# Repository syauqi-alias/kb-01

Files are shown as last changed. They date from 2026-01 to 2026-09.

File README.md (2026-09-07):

# Komputer Basikal, KB-01

**KB-01** is a high-performance, open-source bike computer built around the Raspberry Pi Compute Module 5. Designed to function like a rugged PDA for cycling, it features NVMe storage, precise GNSS tracking, a full sensor cluster for ML-based dead reckoning, and a robust power management system with 4.5–7 hours of estimated runtime.

## 📋 Specifications

| Feature | Component / Detail |
| :--- | :--- |
| **Core** | Raspberry Pi CM5 (4GB RAM, quad Cortex-A76) |
| **Storage** | 250GB NVMe M.2 2230 (PCIe) |
| **Display** | Waveshare 3.5" LCD (MIPI DSI) |
| **GNSS** | ST Teseo-LIV4F with Taoglas FXP611.07.0092C (Passive Antenna) |
| **IMU** | Bosch BMI270 (Accel/Gyro, SPI) |
| **Magnetometer** | ST LIS2MDL (I2C) |
| **Barometer** | Bosch BMP390 (I2C) |
| **Temp/Humidity** | Sensirion SHT40 (I2C) |
| **Wheel Speed** | TI DRV5023FA (Continuous unipolar Hall switch, 30kHz BW) |
| **Battery** | 10,000mAh Li-ion 1160100 (3.7V / 37Wh) |
| **Charger** | TI BQ25895 (I2C-configurable, USB BC1.2 detection) |
| **Fuel Gauge** | Maxim MAX17048 (I2C) |
| **Boost Converter** | TI TPS61022 (5V output, 8A valley current limit) |
| **USB Mux** | TI TS3USB30E (2:1 USB 2.0, auto-switching via BQ25895 DSEL) |
| **User Input** | Rotary encoder (A/B + push) + 2 buttons |
| **Audio** | Passive electromagnetic buzzer (PWM-driven via 2N7002 N-FET) |
| **Connectivity** | USB 2.0 (device/peripheral mode for GPX file transfer + charging) |

## ⚡ Power System

The power architecture handles high current loads from the CM5 and NVMe while ensuring safe battery management.

```
USB-C → BQ25895 (VBUS) → SYS → TPS61022 (VIN) → 5V → CM5
                ↕
            Battery
```

* **Charger / Power Path:** [TI BQ25895](https://www.ti.com/product/BQ25895)
    * Charges the battery while simultaneously powering the system via SYS rail.
    * Integrated USB BC1.2 detection for automatic source identification (SDP/CDP/DCP).
    * Input Current Optimizer (ICO) negotiates maximum power from USB source.
    * Ship mode via BATFET for zero-quiescent shutdown.
* **Fuel Gauge:** [Maxim MAX17048](https://www.analog.com/en/products/max17048.html)
    * ModelGauge algorithm — no sense resistor required.
    * Provides accurate SoC% and voltage reporting over I2C.
* **Boost Converter:** [TI TPS61022](https://www.ti.com/product/TPS61022)
    * Provides a fixed 5V output from 3.0–4.5V battery input.
    * EN tied to VIN (always on when SYS is live); MODE tied to GND (PFM for light-load efficiency).
    * Feedback resistors: R1 = 732kΩ, R2 = 100kΩ (per TI reference design).
* **USB-C:**
    * CC1/CC2: 5.1kΩ pull-downs to GND (sink device).
    * D+/D−: Routed via TS3USB30E multiplexer — Channel 1 to BQ25895 (BC1.2 detection), Channel 2 to CM5 USB (data transfer).
    * Mux control: BQ25895 DSEL pin drives TS3USB30E SEL (automatic, no GPIO needed).
    * CM5 USB configured as device/peripheral via `dtoverlay=dwc2,dr_mode=peripheral`.
* **Battery Life:** ~4.5 hours (max load) to ~7 hours (typical load).

## 🔌 Bus Architecture

| Bus | GPIOs | Devices | Notes |
| :--- | :--- | :--- | :--- |
| **I2C1** | GPIO2/3 | BQ25895, MAX17048 | 1.8kΩ built-in pull-ups (do NOT add external) |
| **I2C2** | GPIO4/5 | LIS2MDL, BMP390, SHT40 | 4.7kΩ external pull-ups required |
| **SPI0** | GPIO8–11 | BMI270 | Mode 0, max 10MHz |
| **UART0** | GPIO14/15 | Teseo-LIV4F | 9600 baud default, TX/RX crossover |
| **DSI0** | DISP0 connector | Waveshare 3.5" | Copied from CM5 IO board |
| **PCIe** | PCIe connector | NVMe SSD | Copied from CM5 IO board |

## 📡 Sensor Cluster & ML Dead Reckoning

The sensor cluster enables ML-based location prediction when GNSS is unavailable (tunnels, dense tree cover, urban canyons).

* **Inputs:** BMI270 (acceleration/rotation), LIS2MDL (heading), BMP390 (altitude), DRV5023FA (wheel speed/distance)
* **Ground truth:** Teseo-LIV4F GNSS position during training
* **Approach:** Extended Kalman filter or RNN; wheel speed removes velocity drift ambiguity
* **Wheel Speed Sensor:** DRV5023FA is a continuous-sensing unipolar Hall switch (not sampled) with 30kHz bandwidth — it never misses a pulse regardless of wheel speed. Single south-facing magnet on spoke, open-drain output with 10kΩ pull-up.

## 🔊 Audio Alerts

A passive electromagnetic buzzer (e.g. MLT-8530) driven by PWM on GPIO7 through a 2N7002 N-channel MOSFET. Used for turn-by-turn navigation alerts, speed warnings, button feedback, and low battery warnings.

```
GPIO7 → 100Ω → gate ──┬── 2N7002 drain ──── Buzzer (−)
                       │                          │
                     10kΩ                     Buzzer (+) → 3.3V
                       │                          │
                      GND              1N4148 ──|◄──┘ (flyback diode)
```

## 🖥️ Software Architecture

* **Language:** C (with pthreads for multi-core)
* **GUI:** LVGL (renders directly to framebuffer, no X11/Wayland)
* **Kernel:** PREEMPT_RT patched Linux for deterministic interrupt handling
* **Core allocation:**
    * Core 0 — UI rendering + wheel speed ISR (highest priority)
    * Core 1 — Sensor acquisition (I2C/SPI reads)
    * Core 2 — GNSS processing (UART/NMEA parsing)
    * Core 3 — ML inference + data logging

## 🛠️ Hardware Design Notes

* **Space Optimization:** The boost converter is placed underneath the M.2 NVMe drive clearance to minimize the PCB footprint.
* **Antenna:** Uses a passive flexible polymer antenna (Taoglas FXP611) for GNSS.
* **Mounting:** Designed to accommodate standard 3.5" display mounting points.
* **GPIO0:** Left as spare — HAT EEPROM pin (I2C0/ID_SD), available for future expansion.

### Layer Stackup (6-layer, 1.6 mm, AISLER)

Stackup source: [AISLER 6-layer 1.6 mm 35 µm](https://community.aisler.net/t/6-layers-1-6mm-35-m-stackup/5458). Copper is 35 µm on all layers. Impedance-controlled nets stay on the outer layers only, referenced to the adjacent solid GND plane (same approach as the Raspberry Pi CM5 IO board).

```
Layer    Role                     Reference   Dielectric below
F.Cu     Signal — low-speed       In1 GND     2 × 2116 prepreg, 230 µm, Er 4.25
In1.Cu   GND plane — never split  —           FR4 core,          300 µm, Er 4.5
In2.Cu   Signal — GPIO / SD / I2C In1 GND     3 × 2116 prepreg, 345 µm, Er 4.25
In3.Cu   Power — split pours      —           FR4 core,          300 µm, Er 4.5
In4.Cu   GND plane — never split  —           2 × 2116 prepreg, 230 µm, Er 4.25
B.Cu     Signal — high-speed      In4 GND     —
```

* **B.Cu (high-speed side):** CM5 module, M.2 NVMe, DSI connector, Teseo GNSS and SMA are all on B.Cu, so PCIe, DSI0 and the GNSS RF trace route bottom-to-bottom with no layer changes. Net classes: `DP_90_Outer` (PCIe, USB 2.0), `DP_100_Outer` (DSI0), `SE_50_Outer` (GNSS RF).
* **F.Cu:** USB-C, charger, fuel gauge, sensors, UI. USB 2.0 D+/D− (J3 → TS3USB30E → BQ25895) stays on F.Cu.
* **In2.Cu:** route predominantly one axis (along the 120 mm dimension) — it faces In3 with no plane between them.
* **In3.Cu:** pours only, no traces: `+5V`, `Vsys`, `+3V3`, `VBUS`, `+1.8v`, `3.3V_GNSS`, `M.2_3v3`.
* **Stitching:** via fence between In1 and In4 along the RF trace and around the CM5 high-speed region. Fill unused In2 area with GND to balance copper against In3.

See [ROUTING.md](ROUTING.md) for the routing order and per-net constraints.

## ⚙️ config.txt

```ini
dtparam=i2c_arm=on
dtoverlay=i2c2-pi5,pins_4_5
dtparam=spi=on
enable_uart=1
dtoverlay=dwc2,dr_mode=peripheral
```

## ⚠️ Disclaimer

This project is currently in the **prototype/brainstorming phase**.

* Battery life estimates (4.5–7 hours) are theoretical and based on datasheet typical values.
* USB-PD is not supported with passive CC resistors (5V input only).
* The CM5 + NVMe combination draws significant power — consider NVMe power states for optimisation.

## 🔗 References & Credits

* Designed by [Syauqi Alias](https://syauqi-alias.github.io/)
* Read the full project log here: [Projects Brainstorming](https://syauqi-alias.github.io/jekyll/2023-06-10-idea.html#komputer-basikal-kb-01-bike-computer)

## 📄 License

[MIT License](LICENSE)

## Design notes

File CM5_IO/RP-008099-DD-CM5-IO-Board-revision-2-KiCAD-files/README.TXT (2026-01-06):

These files have been created in version 9 of KiCAD.

Some of the 3d models need to be downloaded form the following places and put into the CM5IO.3shapes directory some models are approximations.

https://datasheets.raspberrypi.org/cm5/CM5-step.zip
https://www.molex.com/molex/products/part-detail/memory_card_socket/5033981892

The models provided in the 3dmodels directory are from various manufacturers including Diodes, Hirose, MTCONN, Toby, TRXCOM. Terms and conditions for the use of the models remain with the original manufacture.

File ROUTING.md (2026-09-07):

# KB-01 Routing Priority

This document is the order in which to route the KB-01 board, and the constraints for each group of nets.

It assumes the layer stackup in [README.md → Layer Stackup](README.md#layer-stackup-6-layer-16-mm-aisler) and the net classes defined in `KB-01_kicad/KB-01/KB-01.kicad_pro` (`SE_50_Outer`, `DP_90_Outer`, `DP_100_Outer`). Board coordinates below are KiCad board coordinates in mm.

**Principle:** route what cannot bend before what can. RF and differential pairs need straight, unbroken paths on an empty board. GPIO can snake around them later.

```
Tier 0  Planes + CM5 escape   foundation — nothing else is valid without these
Tier 1  GNSS RF               1 net, zero tolerance
Tier 2  PCIe                  3 pairs, tightest matching
Tier 3  DSI0                  5 pairs, clock-to-data matching
Tier 4  Switcher hot loops    tiny, local, but fix component placement
Tier 5  USB 2.0               3 pairs, one crosses sides
Tier 6  Power distribution    wide pours + via arrays
Tier 7  Buses                 SPI, I2C, UART, SD, SUSCLK
Tier 8  GPIO / UI / LEDs      anything goes
   —    Leftovers             do not route — delete from schematic
```

## Layer roles (summary)

```
F.Cu     Signal — low-speed       ref In1 GND
In1.Cu   GND plane — never split
In2.Cu   Signal — GPIO / SD / I2C ref In1 GND
In3.Cu   Power — split pours
In4.Cu   GND plane — never split
B.Cu     Signal — high-speed      ref In4 GND
```

**B.Cu is the high-speed side.** The CM5 module, M.2 socket J8, DSI connector J1, Teseo GNSS U6 and SMA J15 are all on B.Cu. PCIe, DSI0 and the GNSS RF trace route bottom-to-bottom with no layer change.

---

## Tier 0 — Planes and CM5 escape

Do this before the first trace.

- Pour **GND on In1.Cu and In4.Cu**, full board, **no splits**. Every impedance number in the net classes assumes a solid plane directly under the trace.
- Plan the **CM5 escape** (204 pads, B.Cu, roughly X 49–105, Y 97–134).
  - High-speed pairs (PCIe, DSI0, USB) exit straight out on B.Cu.
  - GPIO drops to In2 through vias.
  - Reserve clear B.Cu exit lanes for the high-speed pads. Do not place vias in those lanes.

## Tier 1 — GNSS RF

- Net: `Net-(D5-A1)` — add the net label **`GNSS_RF`** in `gnss.kicad_sch` so the name survives re-annotation.
- Path: **U6 RF_IN → D5 → J15 SMA**, all B.Cu, ~12 mm. U6 at (136.1, 50.2), D5 at (132.4, 43.2), J15 at (132.8, 38.6).
- Class: `SE_50_Outer`, **0.395 mm**, referenced to In4.
- Rules:
  - Straight line. No vias. No bends sharper than 45°.
  - No other copper on B.Cu within ~3× trace width (≈1.2 mm) either side.
  - **Via fence** both sides, B.Cu GND pour to In4, ~1.5 mm pitch.
  - Trace passes **through** the D5 ESD pad; no stub branching off.
- Why first: it is the only net where a 1 mm detour measurably costs receiver sensitivity.

## Tier 2 — PCIe

- Nets: `/CM5_high_speed/PCIE_TX_P/N`, `PCIE_RX_P/N`, `PCIE_CLK_P/N`.
- Path: CM5 (B.Cu) → **J8 M.2** at (92.3, 51.4), ~45 mm, B.Cu.
- Class: `DP_90_Outer`, **0.23 mm / 0.12 mm gap**.
- Rules:
  - **Intra-pair skew ≤ 0.1 mm.** No inter-pair matching needed for a single lane.
  - Zero vias if at all possible — both ends are on B.Cu. If a via is unavoidable, one per line, side by side, with a GND stitching via within 1 mm.
  - Pair-to-pair spacing ≥ 3× gap. Keep clear of the DSI pairs.
- Note: the RPi CM5 IO board uses 0.147 mm on a 90 µm dielectric. KB-01 is wider because AISLER's outer prepreg is 230 µm. That is expected — do not "fix" it.
- M.2 lanes 1–3 are intentionally unconnected. Only lane 0 is wired.

## Tier 3 — DSI0

- Nets: `/CM5_high_speed/DPHY0_C_P/N`, `DPHY0_D0..D3_P/N`.
- Path: CM5 (B.Cu) → **J1** at (70.05, 79.4), B.Cu.
- Class: `DP_100_Outer`, **0.18 mm / 0.13 mm gap**.
- Rules:
  - **Intra-pair ≤ 0.1 mm.**
  - **Data-to-clock lane match within ~0.5 mm.**
  - Stay on B.Cu, no vias.
- Why after PCIe: more pairs, slightly more tolerant — DSI bends around PCIe, not the other way round.

## Tier 4 — Switching converter hot loops

Only a few mm each, but they dictate cap and inductor placement. Route them while parts can still be nudged.

- **TPS61022 boost** — U4 at (88.1, 138.3), L2 at (91.5, 144.3), caps C16–C22, all B.Cu.
  - Loop: SW pin → L2 → VOUT cap → GND → PGND pin.
  - Keep on one layer, shortest possible. Cap GND pads drop straight into In4 with 2+ vias each.
- **BQ25895 charger** — U1 at (115.7, 145.2), L1 at (120.0, 136.8), input/output caps, all F.Cu.
  - Same treatment, referenced to In1.
- **Switch nodes** `Net-(U4-SW)` and `Net-(U10-LX)`: short, fat polygons. Never long traces. Never under the RF trace or the U9 oscillator.

## Tier 5 — USB 2.0

- Nets: `/Battery_charger/USB_D+/−`, `MUX_D+/−`, `CHG_D+/−`.
- Path: **J3 USB-C** (F.Cu, 103.6, 153.0) → **U2 TS3USB30E** (F.Cu, 103.3, 143.7) → **U1 BQ25895** (F.Cu) for BC1.2. All F.Cu, short.
- The mux's second channel goes to the **CM5 on B.Cu** — that one pair crosses sides.
  - Two signal vias side by side.
  - One GND stitching via beside them, so return current has a path from In1 to In4.
- Class: `DP_90_Outer`. **Intra-pair ≤ 0.5 mm** — USB 2.0 is forgiving.

## Tier 6 — Power distribution

Biggest current first.

```
BAT+  J4 (127, 150) → U1          F.Cu polygon, ~11 mm, ≥3 mm wide
VBUS  J3 → U1                     F.Cu polygon, ~13 mm, 2–3 mm wide
Vsys  U1 (F.Cu) → U4 (B.Cu)       F.Cu → In3 pour → B.Cu; via array, 6+ vias 0.8/0.4
+5V   U4 → CM5                    B.Cu polygon, ~5 mm — shortest heavy run on the board
Rails +3V3, +1.8v, 3.3V_GNSS,     In3 split pours, fed from CM5 / regulators,
      M.2_3v3                     delivered to F.Cu consumers via 2 vias each
```

- Vsys crossing sides is where a **via array** genuinely matters — a single via is a ~1 A bottleneck.
- Pour In3 last within this tier, after the outer polygons exist, so it is clear which rails still need an inner path.
- Track-width presets for current are in Board Setup → Pre-defined Sizes (0.5 mm ≈ 2 A … 3.0 mm ≈ 7 A, outer layer, 20 °C rise).

## Tier 7 — Buses (mostly In2.Cu)

- **SPI → BMI270** (U12, F.Cu, 103.6, 79.6). Up to 10 MHz — fastest bus on the board. Keep SCK short, no stubs.
- **I2C** → LIS2MDL, BMP581, SHT40, MAX17048, BQ25895. Star or daisy-chain; keep total SDA/SCL length sensible.
- **UART → Teseo** (CM5 B.Cu → U6 B.Cu). Can stay on B.Cu.
- **SD bus** `SD_CLK/CMD/DAT0–3` → J14 (136.5, 90.6). Route as a bundle, match within ~5 mm.
- **SUSCLK**: U9 32.768 kHz oscillator (B.Cu, 82.9, 60.6) → J8. Short. Keep the trace from heading toward L5 (74.4, 51.5).
- **In2 one-axis rule**: mostly vertical runs (along the 120 mm dimension). Jog horizontally on F.Cu or B.Cu. In2 faces In3 with no plane between them.

## Tier 8 — GPIO, UI, sense lines

- Encoder SW3, key switches SW4/SW5, buzzer LS1, power button SW2, LEDs, PPS.
- **Sense lines** — BQ25895 TS / ILIM, MAX17048 `Fuel_G`: short, away from switch nodes. Otherwise unconstrained.

## Do not route

These nets have no destination on this board. They were carried over from the CM5 IO board copy.

```
HDMI0_*   HDMI1_*   USB3-0-*   USB3-1-*   TRD0..3_*   DPHY1_*  (J13)
```

Delete them from `CM5_high_speed.kicad_sch` and `CM5_GPIO.kicad_sch`, and remove J13, **before Tier 0** — otherwise the CM5 escape plan reserves lanes for dead nets, and DRC flags them as unconnected forever.

## Pre-flight checklist

- [ ] Leftover nets and J13 removed from the schematic
- [ ] `GNSS_RF` net label added in `gnss.kicad_sch`
- [ ] GND pours on In1.Cu and In4.Cu, filled, no splits
- [ ] Board Setup → Net Classes → Assignments resolves PCIe → `DP_90_Outer`, DPHY0 → `DP_100_Outer`, RF → `SE_50_Outer`
- [ ] KiCad closed before any external edit to `.kicad_pro` / `.kicad_pcb` / `.kicad_sch`
- [ ] DRC shows no new errors after each tier

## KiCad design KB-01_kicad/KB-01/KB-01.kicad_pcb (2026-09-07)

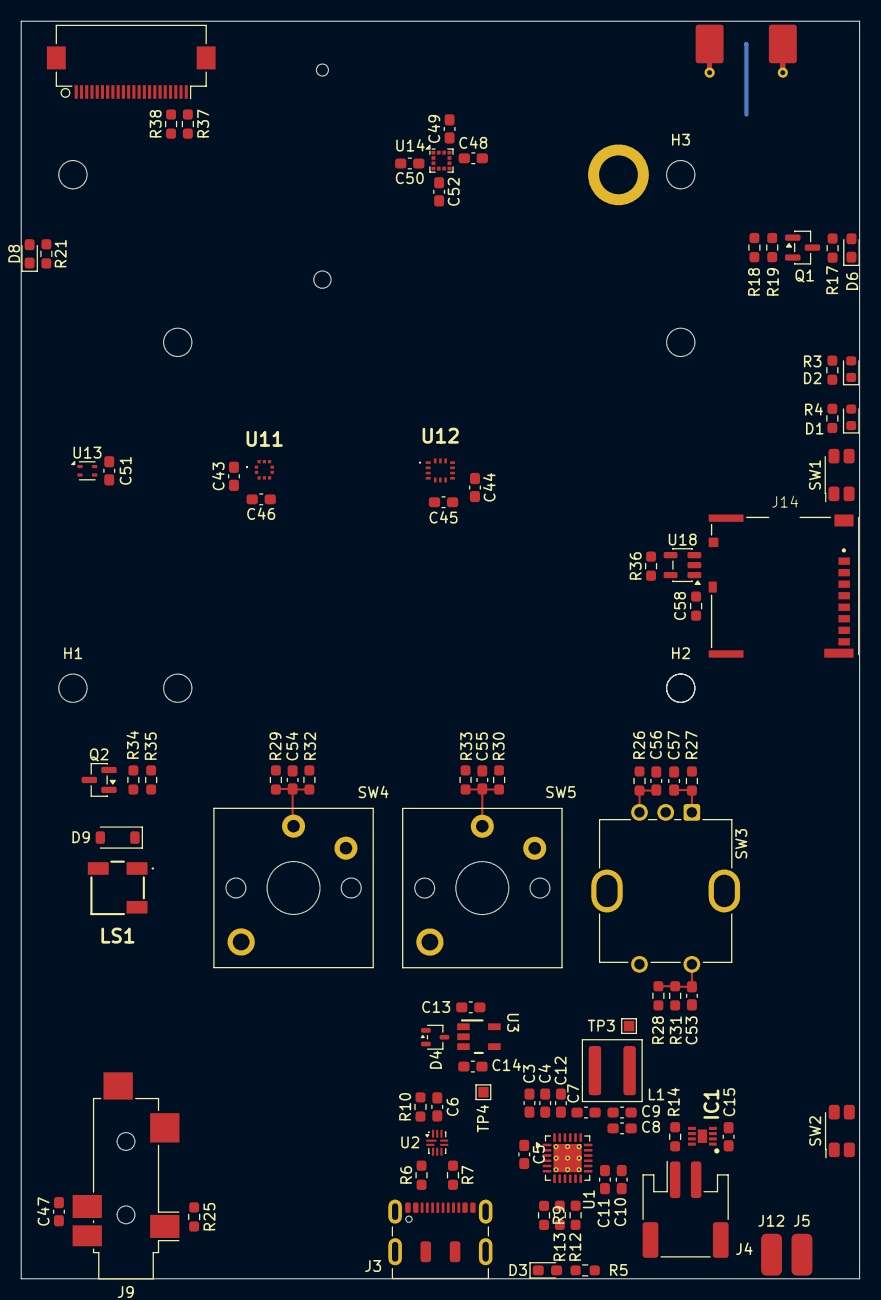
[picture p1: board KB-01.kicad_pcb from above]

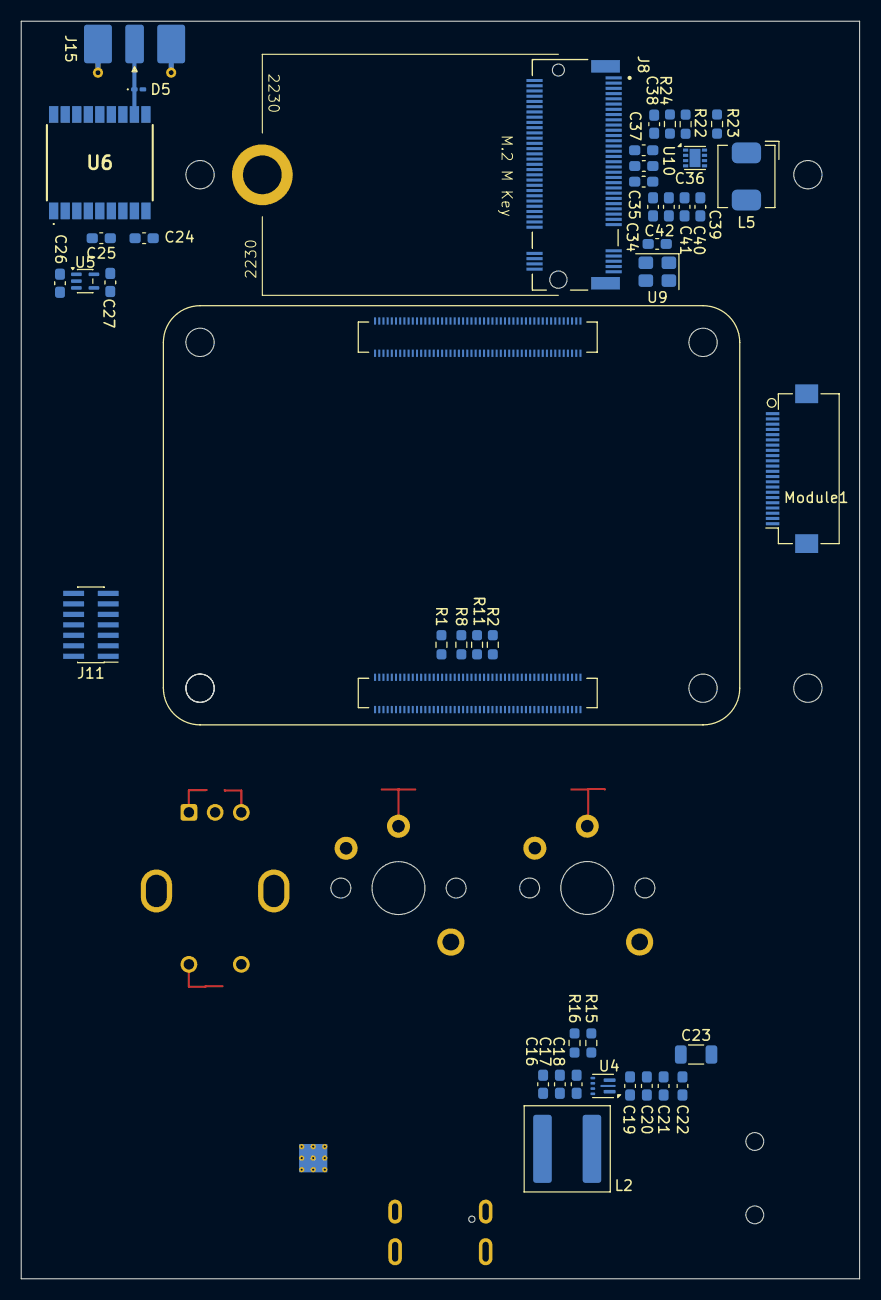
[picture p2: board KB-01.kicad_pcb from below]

Board: 6 copper layers, 80.0 x 120.0 mm, 138 parts (43 on the bottom side), 127 nets.

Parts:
C3, C8, C9, C10: 10uF 25V; C_0603_1608Metric_Pad1.08x0.95mm_HandSolder
C4, C11, C15: 0.1uF 25V; C_0603_1608Metric_Pad1.08x0.95mm_HandSolder
C5, C13: 1uF 25V; C_0603_1608Metric_Pad1.08x0.95mm_HandSolder
C6, C34, C37, C47: 0.1uF 10V; C_0603_1608Metric_Pad1.08x0.95mm_HandSolder
C7: 47nF 25V; C_0603_1608Metric_Pad1.08x0.95mm_HandSolder
C12, C14: 4.7uF 16V; C_0603_1608Metric_Pad1.08x0.95mm_HandSolder
C16, C17, C19, C20, C21, C22: 22uF 16V; C_0603_1608Metric_Pad1.08x0.95mm_HandSolder
C18: 0.1uF 16V; C_0603_1608Metric_Pad1.08x0.95mm_HandSolder
C23: 47uF 16V; R_1206_3216Metric
C24, C43, C44, C45, C46, C48, C50, C51, C53, C54, C55, C56, C57: 100nF 6.3V; C_0603_1608Metric_Pad1.08x0.95mm_HandSolder
C25, C49: 10uF 6.3V; C_0603_1608Metric_Pad1.08x0.95mm_HandSolder
C26, C27: 1uF 16V; C_0603_1608Metric_Pad1.08x0.95mm_HandSolder
C35, C36, C39, C40, C41, C42: 10uF10V; C_0603_1608Metric_Pad1.08x0.95mm_HandSolder
C38: 4.7nF 10V; C_0603_1608Metric_Pad1.08x0.95mm_HandSolder
C52: 220nF 25V; C_0603_1608Metric_Pad1.08x0.95mm_HandSolder
C58: 10uF 6.3V; R_0603_1608Metric_Pad0.98x0.95mm_HandSolder
D1: LED Green; LED_0603_1608Metric
D2: LED Red; LED_0603_1608Metric
D3, D8: Green; D_0603_1608Metric_Pad1.05x0.95mm_HandSolder
D4: BAT54-05W; SOT-323_SC-70
D5: SM15T36CA; D_0201_0603Metric_Pad0.64x0.40mm_HandSolder
D6: LED Red; LED_0603_1608Metric_Pad1.05x0.95mm_HandSolder
D9: 1N4148W; D_SOD-123
H1, H2, H3, H4: MountingHole; MountingHole_2.7mm_M2.5_DIN965
IC1: MAX17048G+T10; SON50P200X200X80-9N-D
J1, J13: Conn_01x22_MountingPin; Hirose_FH12-22S-0.5SH_1x22-1MP_P0.50mm_Horizontal
J3: USB_C_Receptacle_USB2.0_14P; USB_C_Receptacle_JAE_DX07S016JA1R1500
J4: Conn_01x02_MountingPin; JST_PH_S2B-PH-SM4-TB_1x02-1MP_P2.00mm_Horizontal
J5, J12: Conn_01x01_Socket; SolderWirePad_1x01_SMD_2x4mm
J8: Bus_M.2_Socket_M; M.2 M Key socket
J9: AudioJack3_SwitchTR; Jack_3.5mm_CUI_SJ2-3593D-SMT_Horizontal
J11: Conn_02x07_Odd_Even; PinHeader_2x07_P1.00mm_Vertical_SMD
J14: Micro_SD_Card_Det; SDCARD_MOLEX_503398-1892
J15: Conn_Coaxial; SMA_Molex_73251-2120_EdgeMount_Horizontal
L1: 1.0uH; L_Coilcraft_XAL5030-XXX
L2: 1uH 21.8A; L_Coilcraft_XAL7030-102
L5: 2.2uH; L_Bourns_SRP5030CC
LS1: CMT-0502-03-SMT-TR; CMT050203SMTTR
Module1: ComputeModule5-CM5; Raspberry-Pi-5-Compute-Module
Q1: MMBT3904; SOT-23
Q2: 2N7002; SOT-23
R1, R2, R18: 4.7k; R_0603_1608Metric_Pad0.98x0.95mm_HandSolder
R3, R4, R21, R31, R32, R33: 1k; R_0603_1608Metric_Pad0.98x0.95mm_HandSolder
R5: 2.21K; R_0603_1608Metric_Pad0.98x0.95mm_HandSolder
R6, R7: 5.1k; R_0603_1608Metric_Pad0.98x0.95mm_HandSolder
R8, R10, R11, R12, R13, R14, R19, R25, R26, R27, R28, R29, R30, R35: 10k; R_0603_1608Metric_Pad0.98x0.95mm_HandSolder
R9: 133; R_0603_1608Metric_Pad0.98x0.95mm_HandSolder
R15: 750k; R_0603_1608Metric_Pad0.98x0.95mm_HandSolder
R16: 100k; R_0603_1608Metric_Pad0.98x0.95mm_HandSolder
R17: 330; R_0603_1608Metric_Pad0.98x0.95mm_HandSolder
R22, R36: 10K 1%; R_0603_1608Metric_Pad0.98x0.95mm_HandSolder
R23: 100k 1%; R_0603_1608Metric_Pad0.98x0.95mm_HandSolder
R24, R37, R38: 2.2K 1%; R_0603_1608Metric_Pad0.98x0.95mm_HandSolder
R34: 180; R_0603_1608Metric_Pad0.98x0.95mm_HandSolder
SW1: Right angle Tact button; SW_SPST_EVQP7A
SW2: Power button; SW_SPST_EVQP7A
SW3: RotaryEncoder_Switch_MP; RotaryEncoder_Bourns_Vertical_PEC12R-3x17F-Sxxxx
SW4, SW5: SW_Push; SW_Kailh_Choc_V1V2_1.00u
TP3, TP4: TestPoint; TestPoint_Pad_1.0x1.0mm
U1: BQ25895; Texas_RTW_WQFN-24-1EP_4x4mm_P0.5mm_EP2.7x2.7mm_ThermalVias
U2: TS3USB30ERSWR; UQFN-10_1.4x1.8mm_P0.4mm
U3: TLV70430DBVR; DBV0005A_M
U4: TPS61022; Texas_RWU0007A_VQFN-7_2x2mm_P0.5mm
U5: TLV773_SOT353; SOT-353_SC-70-5
U6: TESEO-LIV4F; TESEOLIV4FTR
U9: ASEK-32.768KHZ-L-R-T; Crystal_SMD_3225-4Pin_3.2x2.5mm
U10: AP3441SHE-7B; DFN-8-1EP_2x2mm_P0.5mm_EP1.05x1.75mm
U11: BMP581
U12: BMI270
U13: SHT40; Sensirion_DFN-4_1.5x1.5mm_P0.8mm_SHT4x_NoCentralPad
U14: LIS2MDL; LGA-12_2x2mm_P0.5mm
U18: RT9742GGJ5 / NCP380HSN10AAT1G; SOT-23-5

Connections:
+3V3: C43.2, C44.1, C45.1, C46.1, C47.1, C48.1, C49.1, C50.1, C51.1, D1.2 (A), D2.2 (A), D9.1 (K), J1.22, J9.R, J9.RN, J13.22, LS1.1 (+), Module1.78 (GPIO_VREF(1.8v/3.3v_Input)), Module1.84 (+3.3v_(Output)), Module1.86 (+3.3v_(Output)), R1.1, R2.1, R25.1, R26.1, R27.1, R28.1, R29.1, R30.1, R36.1, R37.1, R38.1, U11.1 (VDDIO), U11.5 (SDO), U11.6 (CSB), U11.10 (VDD), U12.5 (VDDIO), U12.8 (VDD), U13.3 (VDD), U14.3 (~CS), U14.9 (Vdd), U14.10 (Vdd_IO), U18.5 (IN)
+3V_CHRG: C6.1, C14.1, Module1.76 (VBAT), R8.1, R10.2, R14.1, TP4.1 (1_1), U2.9 (VCC), U3.3 (OUT)
+5V: C19.1, C20.1, C21.1, C22.1, C23.1, C26.1, C35.1, C36.1, C37.1, Module1.77 (+5v_(Input)), Module1.79 (+5v_(Input)), Module1.81 (+5v_(Input)), Module1.83 (+5v_(Input)), Module1.85 (+5v_(Input)), Module1.87 (+5v_(Input)), R15.1, U4.3 (VOUT), U5.1 (IN), U10.3 (VIN)
/Battery_charger/CHG_D+: U1.2 (D+), U2.1 (D1+)
/Battery_charger/CHG_D-: U1.3 (D-), U2.7 (D1-)
/Battery_charger/Fuel_G: C10.1, C11.1, C15.1, D4.2 (A), IC1.2 (CELL), IC1.3 (VDD), J4.1, U1.13 (BAT), U1.14 (BAT)
/Battery_charger/MUX_D+: Module1.105 (USB2_P), U2.2 (D2+)
/Battery_charger/MUX_D-: Module1.103 (USB2_N), U2.6 (D2-)
/Battery_charger/RESET: SW2.2, U1.12 (~QON)
/Battery_charger/SEL: R10.1, U1.24 (DSEL), U2.10 (S)
/Battery_charger/USB_D+: J3.A6 (D+), J3.B6 (D+), U2.5 (D-)
/Battery_charger/USB_D-: J3.A7 (D-), J3.B7 (D-), U2.3 (D+)
/Battery_charger/Vsys: C8.1, C9.1, C16.1, C17.1, C18.1, L1.2, L2.1, R5.2, TP3.1 (1_1), U1.15 (SYS), U1.16 (SYS), U4.5 (EN), U4.7 (VIN)
/CM5_GPIO/+1.8v: Module1.88 (+1.8v_(Output)), Module1.90 (+1.8v_(Output))
/CM5_GPIO/CAM_GPIO0: J13.17, Module1.97 (CAM_GPIO0)
/CM5_GPIO/CAM_GPIO1: J9.S, Module1.100 (CAM_GPIO1), R25.2
/CM5_GPIO/EEPROM_nWP: J11.4, Module1.20 (EEPROM_nWP)
/CM5_GPIO/GPIO2: IC1.8 (SDA), Module1.58 (GPIO2), U1.6 (SDA)
/CM5_GPIO/GPIO3: IC1.7 (SCL), Module1.56 (GPIO3), U1.5 (SCL)
/CM5_GPIO/GPIO4: Module1.54 (GPIO4), R2.2, U11.4 (SDI), U13.1 (SDA), U14.4 (SDA/SDI/SDO)
/CM5_GPIO/GPIO5: Module1.34 (GPIO5), R1.2, U11.2 (SCK), U13.2 (SCL), U14.1 (SCL/SPC)
/CM5_GPIO/GPIO6: Module1.30 (GPIO6), R33.1
/CM5_GPIO/GPIO7: Module1.37 (GPIO7), R34.1
/CM5_GPIO/GPIO8: Module1.39 (GPIO8), U12.12 (CSB)
/CM5_GPIO/GPIO9: Module1.40 (GPIO9), U12.1 (SDO)
/CM5_GPIO/GPIO10: Module1.44 (GPIO10), U12.14 (SDX)
/CM5_GPIO/GPIO11: Module1.38 (GPIO11), U12.13 (SCX)
/CM5_GPIO/GPIO12: C57.1, Module1.31 (GPIO12), R27.2, SW3.A
/CM5_GPIO/GPIO13: C56.1, Module1.28 (GPIO13), R26.2, SW3.B
/CM5_GPIO/GPIO14: Module1.55 (GPIO14), U6.3 (UART-RX)
/CM5_GPIO/GPIO15: Module1.51 (GPIO15), U6.2 (UART-TX)
/CM5_GPIO/GPIO16: Module1.29 (GPIO16), U6.9 (~RESET)
/CM5_GPIO/GPIO17: Module1.50 (GPIO17), R11.1, U1.9 (~CE)
/CM5_GPIO/GPIO18: Module1.49 (GPIO18), R31.2
/CM5_GPIO/GPIO19: Module1.26 (GPIO19), R32.1
/CM5_GPIO/GPIO20: Module1.27 (GPIO20), U6.5 (WAKEUP)
/CM5_GPIO/GPIO21: Module1.25 (GPIO21), U5.3 (EN)
/CM5_GPIO/GPIO22: IC1.5 (~ALRT), Module1.46 (GPIO22), R14.2
/CM5_GPIO/GPIO23: Module1.47 (GPIO23), U12.4 (INT1)
/CM5_GPIO/GPIO24: Module1.45 (GPIO24), U14.7 (DRDY)
/CM5_GPIO/GPIO25: Module1.41 (GPIO25), U11.7 (INT)
/CM5_GPIO/GPIO26: Module1.24 (GPIO26), U12.9 (INT2)
/CM5_GPIO/GPIO27: Module1.48 (GPIO27), R8.2, U1.7 (~INT)
/CM5_GPIO/ID_SC: J13.20, Module1.35 (ID_SC), R38.2
/CM5_GPIO/ID_SD: J13.21, Module1.36 (ID_SD), R37.2
/CM5_GPIO/PMIC_ENABLE: J11.12, Module1.99 (PMIC_ENABLE)
/CM5_GPIO/PWR_BUT: J11.14, Module1.92 (PWR_BUT), SW1.1
/CM5_GPIO/SD_CLK: J14.5 (CLK), Module1.57 (SD_CLK)
/CM5_GPIO/SD_CMD: J14.3 (CMD), Module1.62 (SD_CMD)
/CM5_GPIO/SD_DAT0: J14.7 (DAT0), Module1.63 (SD_DAT0)
/CM5_GPIO/SD_DAT1: J14.8 (DAT1), Module1.67 (SD_DAT1)
/CM5_GPIO/SD_DAT2: J14.1 (DAT2), Module1.69 (SD_DAT2)
/CM5_GPIO/SD_DAT3: J14.2 (DAT3/CD), Module1.61 (SD_DAT3)
/CM5_GPIO/SD_PWR: C58.1, J14.4 (VDD), U18.1 (OUT)
/CM5_GPIO/SD_PWR_ON: Module1.75 (SD_PWR_ON), R36.2, U18.4 (EN)
/CM5_GPIO/SYNC_OUT: J11.6, Module1.18 (Ethernet_SYNC_OUT(3.3v))
/CM5_GPIO/USBOTG: J11.10, Module1.101 (USB_OTG_ID)
/CM5_GPIO/nPWR_LED: Module1.95 (LED_nPWR), R3.2
/CM5_GPIO/nRPIBOOT: J11.2, Module1.93 (nRPIBOOT)
/CM5_high_speed/DPHY0_C_N: J1.8, Module1.127 (MIPI0_C_N)
/CM5_high_speed/DPHY0_C_P: J1.9, Module1.129 (MIPI0_C_P)
/CM5_high_speed/DPHY0_D0_N: J1.2, Module1.115 (MIPI0_D0_N)
/CM5_high_speed/DPHY0_D0_P: J1.3, Module1.117 (MIPI0_D0_P)
/CM5_high_speed/DPHY0_D1_N: J1.5, Module1.121 (MIPI0_D1_N)
/CM5_high_speed/DPHY0_D1_P: J1.6, Module1.123 (MIPI0_D1_P)
/CM5_high_speed/DPHY0_D2_N: J1.11, Module1.133 (MIPI0_D2_N)
/CM5_high_speed/DPHY0_D2_P: J1.12, Module1.135 (MIPI0_D2_P)
/CM5_high_speed/DPHY0_D3_N: J1.14, Module1.139 (MIPI0_D3_N)
/CM5_high_speed/DPHY0_D3_P: J1.15, Module1.141 (MIPI0_D3_P)
/CM5_high_speed/DPHY1_C_N: J13.8, Module1.187 (MIPI1_C_N)
/CM5_high_speed/DPHY1_C_P: J13.9, Module1.189 (MIPI1_C_P)
/CM5_high_speed/DPHY1_D0_N: J13.2, Module1.175 (MIPI1_D0_N)
/CM5_high_speed/DPHY1_D0_P: J13.3, Module1.177 (MIPI1_D0_P)
/CM5_high_speed/DPHY1_D1_N: J13.5, Module1.181 (MIPI1_D1_N)
/CM5_high_speed/DPHY1_D1_P: J13.6, Module1.183 (MIPI1_D1_P)
/CM5_high_speed/DPHY1_D2_N: J13.11, Module1.193 (MIPI1_D2_N)
/CM5_high_speed/DPHY1_D2_P: J13.12, Module1.195 (MIPI1_D2_P)
/CM5_high_speed/DPHY1_D3_N: J13.14, Module1.194 (MIPI1_D3_N)
/CM5_high_speed/DPHY1_D3_P: J13.15, Module1.196 (MIPI1_D3_P)
/CM5_high_speed/PCIE_CLK_N: J8.53 (REFCLKn), Module1.112 (PCIe_CLK_N)
/CM5_high_speed/PCIE_CLK_P: J8.55 (REFCLKp), Module1.110 (PCIe_CLK_P)
/CM5_high_speed/PCIE_PWR_EN: Module1.106 (PCIE_PWR_EN), R23.1, U10.7 (EN)
/CM5_high_speed/PCIE_RX_N: J8.43 (PETp0), Module1.118 (PCIe_RX_N)
/CM5_high_speed/PCIE_RX_P: J8.41 (PETn0), Module1.116 (PCIe_RX_P)
/CM5_high_speed/PCIE_TX_N: J8.49 (PERp0), Module1.124 (PCIe_TX_N)
/CM5_high_speed/PCIE_TX_P: J8.47 (PERn0), Module1.122 (PCIe_TX_P)
/CM5_high_speed/PCIE_nCLKREQ: J8.52 (~CLKREQ), Module1.102 (PCIe_nCLKREQ)
/CM5_high_speed/PCIE_nRST: J8.50 (~PERST), Module1.109 (PCIe_nRST)
/CM5_high_speed/PCIE_nWAKE: J8.54 (~PEWAKE), Module1.104 (PCIE_nWAKE)
/CM5_high_speed/SCL0: J1.20, Module1.80 (SCL0)
/CM5_high_speed/SDA0: J1.21, Module1.82 (SDA0)
/GNSS/3.3V_GNSS: C24.1, C25.1, C27.1, R17.1, U5.5 (OUT), U6.6 (VBAT), U6.8 (VCC)
/GNSS/GNSS_PPS: R18.1, U6.4 (PPS)
/PCIe_NVMe/FB: C38.2, R22.2, R24.1, U10.1 (FB)
/PCIe_NVMe/M.2_3v3: C34.1, C38.1, C39.1, C40.1, C41.1, C42.1, D8.2 (A), J8.2 (3.3V), J8.4 (3.3V), J8.12 (3.3V), J8.14 (3.3V), J8.16 (3.3V), J8.18 (3.3V), J8.70 (3.3V), J8.72 (3.3V), J8.74 (3.3V), L5.2, R22.1, U9.1 (EN), U9.4 (VDD)
GND: C3.2, C4.2, C5.2, C6.2, C8.2, C9.2, C10.2, C11.2, C12.2, C13.2, C14.2, C15.2, C16.2, C17.2, C18.2, C19.2, C20.2, C21.2, C22.2, C23.2, C24.2, C25.2, C26.2, C27.2, C34.2, C35.2, C36.2, C37.2, C39.2, C40.2, C41.2, C42.2, C43.1, C44.2, C45.2, C46.2, C47.2, C48.2, C49.2, C50.2, C51.2, C52.2, C53.2, C54.2, C55.2, C56.2, C57.2, C58.2, D5.2 (A2), IC1.1 (CTG), IC1.4 (GND), IC1.6 (QSTRT), IC1.9 (EP), J1.1, J1.4, J1.7, J1.10, J1.13, J1.16, J1.19, J1.MP (MountPin), J3.A1 (GND), J3.A12 (GND), J3.B1 (GND), J3.B12 (GND), J3.S1 (SHIELD), J4.2, J4.MP (MountPin), J8.1 (GND), J8.3 (GND), J8.9 (GND), J8.15 (GND), J8.21 (GND), J8.27 (GND), J8.33 (GND), J8.39 (GND), J8.45 (GND), J8.51 (GND), J8.57 (GND), J8.71 (GND), J8.73 (GND), J8.75 (GND), J8.M1 (GND2230), J8.S1, J8.S2, J9.T, J9.TN, J11.1, J11.3, J11.5, J11.7, J11.9, J11.11, J11.13, J12.1 (Pin_1_1), J13.1, J13.4, J13.7, J13.10, J13.13, J13.16, J13.19, J13.MP (MountPin), J14.6 (VSS), J14.11 (SHIELD), J15.2 (Ext), Module1.1 (GND), Module1.2 (GND), Module1.7 (GND), Module1.8 (GND), Module1.13 (GND), Module1.14 (GND), Module1.22 (GND), Module1.23 (GND), Module1.32 (GND), Module1.33 (GND), Module1.42 (GND), Module1.43 (GND), Module1.52 (GND), Module1.53 (GND), Module1.59 (GND), Module1.60 (GND), Module1.65 (GND), Module1.66 (GND), Module1.71 (GND), Module1.74 (GND), Module1.98 (GND), Module1.107 (GND), Module1.108 (GND), Module1.113 (GND), Module1.114 (GND), Module1.119 (GND), Module1.120 (GND), Module1.125 (GND), Module1.126 (GND), Module1.131 (GND), Module1.132 (GND), Module1.137 (GND), Module1.138 (GND), Module1.144 (GND), Module1.150 (GND), Module1.155 (GND), Module1.156 (GND), Module1.161 (GND), Module1.162 (GND), Module1.167 (GND), Module1.168 (GND), Module1.173 (GND), Module1.174 (GND), Module1.179 (GND), Module1.180 (GND), Module1.185 (GND), Module1.186 (GND), Module1.191 (GND), Module1.192 (GND), Module1.197 (GND), Module1.198 (GND), Q1.2 (E), Q2.2 (S), R6.2, R7.1, R9.2, R11.2, R13.2, R16.2, R19.2, R23.2, R24.2, R35.1, SW1.2, SW2.1, SW3.C, SW3.MP, SW3.S2, SW4.2, SW5.2, U1.8 (OTG), U1.17 (PGND), U1.18 (PGND), U1.25 (PGND), U2.4 (GND), U2.8 (~OE), U3.1 (GND), U3.4 (NC), U3.5 (NC), U4.1 (GND), U4.6 (MODE), U5.2 (GND), U6.1 (GND), U6.10 (GND_RF), U6.12 (GND_RF), U9.2 (GND), U10.4 (PGND), U10.8 (SGND), U10.9 (PAD), U11.3 (VSS_1), U11.8 (VSS_2), U11.9 (VSS_3), U12.6 (GNDIO), U12.7 (GND), U13.4 (VSS), U14.6 (GND), U14.8 (GND), U18.2 (GND)
unnamed: C7.1, L1.1, U1.19 (SW), U1.20 (SW)
unnamed: C53.1, R28.2, R31.1, SW3.S1
unnamed: C54.1, R29.2, R32.2, SW4.1
unnamed: C55.1, R30.2, R33.2, SW5.1
unnamed: D1.1 (K), R4.1
unnamed: D2.1 (K), R3.1
unnamed: D3.2 (A), R5.1
unnamed: D3.1 (K), U1.4 (STAT)
unnamed: C13.1, D4.3 (K), U3.2 (IN)
unnamed: D5.1 (A1), J15.1 (In), U6.11 (RF_IN)
unnamed: D6.2 (A), R17.2
unnamed: D6.1 (K), Q1.3 (C)
unnamed: D8.1 (K), R21.1
unnamed: D9.2 (A), LS1.2 (-), Q2.3 (D)
unnamed: J3.A5 (CC1), R6.1
unnamed: J3.B5 (CC2), R7.2
unnamed: J5.1 (Pin_1_1), R12.2, R13.1, U1.11 (TS)
unnamed: J8.10 (DAS/~DSS/~LED1), R21.2
unnamed: J8.68 (SUSCLK), U9.3 (Out)
unnamed: Module1.21 (LED_nACT), R4.2
unnamed: Q1.1 (B), R18.2, R19.1
unnamed: Q2.1 (G), R34.2, R35.2
unnamed: C7.2, U1.21 (BTST)
unnamed: R9.1, U1.10 (ILIM)
unnamed: C3.1, C4.1, U1.23 (PMID)
unnamed: C12.1, R12.1, U1.22 (REGN)
unnamed: R15.2, R16.1, U4.4 (FB)
unnamed: L2.2, U4.2 (SW)
unnamed: L5.1, U10.6 (LX)
unnamed: C52.1, U14.5 (C1)
VBUS: C5.1, D4.1 (A), J3.A4 (VBUS), J3.A9 (VBUS), J3.B4 (VBUS), J3.B9 (VBUS), U1.1 (VBUS)

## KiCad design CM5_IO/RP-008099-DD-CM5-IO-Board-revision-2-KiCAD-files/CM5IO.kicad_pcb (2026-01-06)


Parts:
C9, C18: 100n; C_0402_1005Metric; Part Description 0.1uF 10% 16V Ceramic Capacitor X7R 040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
H1, H2, H3, H4, H5, H6, H7, H8: MountingHole; MountingHole_2.7mm_M2.5_DIN965; Part Description M2.5 mounting hole; not fitted
J11: USB_C_Receptacle_USB2.0; USB_C_Receptacle_GCT_USB4105-xx-A_16P_TopMnt_Horizontal; Part Description USBC USB2 data and power connector
R9: 2.2K 1%; R_0402_1005Metric; Part Description Resistor 2.2K M1005 1% 63mW

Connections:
/+5v: C9.1, C18.1, J11.A4 (VBUS), J11.A9 (VBUS), J11.B4 (VBUS), J11.B9 (VBUS), R9.1; also elsewhere on the board
/CC1: J11.A5 (CC1); also elsewhere on the board
/CC2: J11.B5 (CC2); also elsewhere on the board
/USB2_N: J11.A7 (D-), J11.B7 (D-); also elsewhere on the board
/USB2_P: J11.A6 (D+), J11.B6 (D+); also elsewhere on the board
GND: C9.2, C18.2, J11.A1 (GND), J11.A12 (GND), J11.B1 (GND), J11.B12 (GND), J11.S1 (SHIELD), R9.2; also elsewhere on the board

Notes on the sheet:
Connectors ------- Ethernet SDCARD 40way RPI Jumpers Fan Battery
Connectors ------ M2 MKey
Discharge Resistor Needed by some Type C PSUs
TypeC Power connector
Connectors ------- HDMI 0 HDMI 1 CSI/DSI 0 CSI/DSI 1

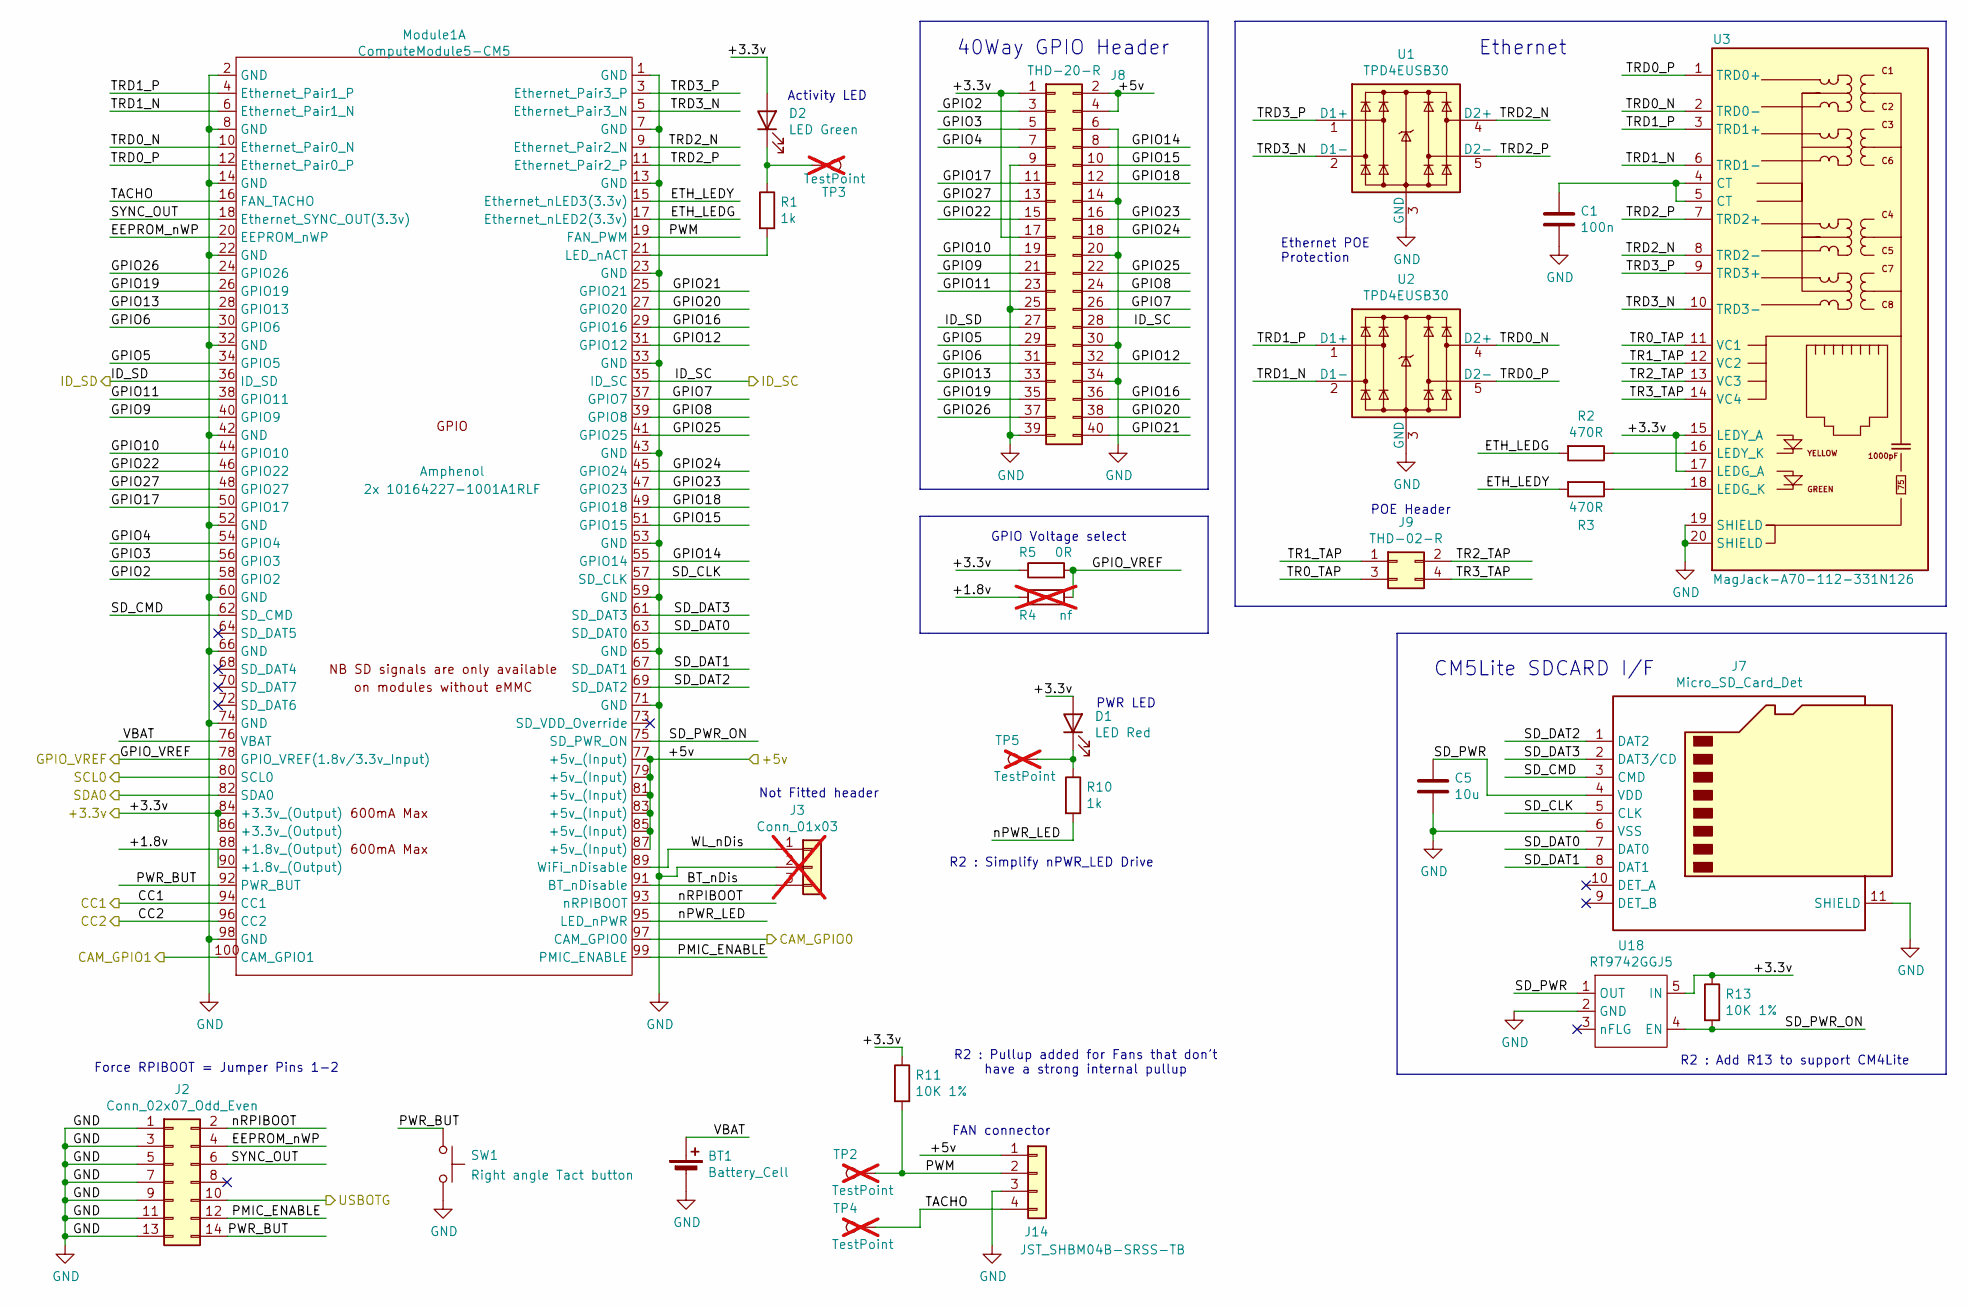
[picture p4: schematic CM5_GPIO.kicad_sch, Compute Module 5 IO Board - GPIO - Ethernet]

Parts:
BT1: Battery_Cell; BatteryHolder_Keystone_3034_1x20mm; Part Description Battery Retainer Coin, 20.0mm 1 Cell SM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
C1: 100n; C_0402_1005Metric; Part Description 0.1uF 10% 16V Ceramic Capacitor X7R 040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
C5: 10u; C_0805_2012Metric; Part Description 10uF 10% 10V Ceramic Capacitor X7R 0805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
D1: LED Red; LED_0603_1608Metric; Part Description Red 620nm LED Indication - Discrete 2.2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
D2: LED Green; LED_0603_1608Metric; Part Description Green 572nm LED Indication - Discrete 2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
J2: Conn_02x07_Odd_Even; PinHeader_2x07_P2.54mm_Vertical; Part Description PinHeader_2x07_P2.54mm_Vertical
J3: Conn_01x03; PinHeader_1x03_P2.54mm_Vertical; Part Description 3pin 0.1" connector; not fitted
J7: Micro_SD_Card_Det; SDCARD_MOLEX_503398-1892; Part Description 9 (8 + 1) Position Card Connector micro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
J8: THD-20-R; PinHeader_2x20_P2.54mm_Vertical; Part Description PinHeader_2x20_P2.54mm_Vertical
J9: THD-02-R; PinHeader_2x02_P2.54mm_Vertical; Part Description PinHeader_2x02_P2.54mm_Vertical
J14: JST_SHBM04B-SRSS-TB; JST_SH_BM04B-SRSS-TB_1x04-1MP_P1.00mm_Vertical; Part Description 4 pin vertical 1mm pitch connector
Module1: ComputeModule5-CM5; Raspberry-Pi-5-Compute-Module; Part Description 100 Position Connector Receptacle, Cent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
R1, R10: 1k; R_0402_1005Metric; Part Description Resistor 1K M1005 1% 63mW
R2, R3: 470R; R_0402_1005Metric; Part Description Resistor 470R M1005 1% 63mW
R4: nf; R_0805_2012Metric_Pad1.20x1.40mm_HandSolder; not fitted
R5: 0R; R_0805_2012Metric_Pad1.20x1.40mm_HandSolder; Part Description Resistor 0R M2012 5%
R11, R13: 10K 1%; R_0402_1005Metric; Part Description Resistor 10K M1005 1% 63mW
SW1: Right angle Tact button; SW_Tactile_SPST_Angled_PTS645Vx58-2LFS; Part Description Right angle through hole Tact switch
TP2, TP3, TP4, TP5: TestPoint; TestPoint_Pad_2.0x2.0mm; Part Description Test point; not fitted
U1, U2: TPD4EUSB30; USON-10_2.5x1.0mm_P0.5mm; Part Description Quad TVS diode for high speed signals (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
U3: MagJack-A70-112-331N126; TRJG0926HENL; Part Description Gigabit Ethernet Magjack
U18: RT9742GGJ5; SOT-23-5; Part Description Power Switch/Driver 1:1 N-Channel 1A TS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

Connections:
/+3.3v: D1.2 (A), D2.2 (A), J8.1, J8.17, Module1.84 (+3.3v_(Output)), Module1.86 (+3.3v_(Output)), R5.1, R11.1, R13.1, U3.15 (LEDY_A), U3.17 (LEDG_A), U18.5 (IN); also elsewhere on the board
/+5v: J8.2, J8.4, J14.1, Module1.77 (+5v_(Input)), Module1.79 (+5v_(Input)), Module1.81 (+5v_(Input)), Module1.83 (+5v_(Input)), Module1.85 (+5v_(Input)), Module1.87 (+5v_(Input)); also elsewhere on the board
/CC1: Module1.94 (CC1); also elsewhere on the board
/CC2: Module1.96 (CC2); also elsewhere on the board
/CM5_GPIO ( Ethernet, GPIO, SDCARD)/+1.8v: Module1.88 (+1.8v_(Output)), Module1.90 (+1.8v_(Output)), R4.1
/CM5_GPIO ( Ethernet, GPIO, SDCARD)/BT_nDis: J3.3, Module1.91 (BT_nDisable)
/CM5_GPIO ( Ethernet, GPIO, SDCARD)/CAM_GPIO0: Module1.97 (CAM_GPIO0); also elsewhere on the board
/CM5_GPIO ( Ethernet, GPIO, SDCARD)/CAM_GPIO1: Module1.100 (CAM_GPIO1); also elsewhere on the board
/CM5_GPIO ( Ethernet, GPIO, SDCARD)/EEPROM_nWP: J2.4, Module1.20 (EEPROM_nWP)
/CM5_GPIO ( Ethernet, GPIO, SDCARD)/ETH_LEDG: Module1.17 (Ethernet_nLED2(3.3v)), R2.2
/CM5_GPIO ( Ethernet, GPIO, SDCARD)/ETH_LEDY: Module1.15 (Ethernet_nLED3(3.3v)), R3.2
/CM5_GPIO ( Ethernet, GPIO, SDCARD)/GPIO2: J8.3, Module1.58 (GPIO2)
/CM5_GPIO ( Ethernet, GPIO, SDCARD)/GPIO3: J8.5, Module1.56 (GPIO3)
/CM5_GPIO ( Ethernet, GPIO, SDCARD)/GPIO4: J8.7, Module1.54 (GPIO4)
/CM5_GPIO ( Ethernet, GPIO, SDCARD)/GPIO5: J8.29, Module1.34 (GPIO5)
/CM5_GPIO ( Ethernet, GPIO, SDCARD)/GPIO6: J8.31, Module1.30 (GPIO6)
/CM5_GPIO ( Ethernet, GPIO, SDCARD)/GPIO7: J8.26, Module1.37 (GPIO7)
/CM5_GPIO ( Ethernet, GPIO, SDCARD)/GPIO8: J8.24, Module1.39 (GPIO8)
/CM5_GPIO ( Ethernet, GPIO, SDCARD)/GPIO9: J8.21, Module1.40 (GPIO9)
/CM5_GPIO ( Ethernet, GPIO, SDCARD)/GPIO10: J8.19, Module1.44 (GPIO10)
/CM5_GPIO ( Ethernet, GPIO, SDCARD)/GPIO11: J8.23, Module1.38 (GPIO11)
/CM5_GPIO ( Ethernet, GPIO, SDCARD)/GPIO12: J8.32, Module1.31 (GPIO12)
/CM5_GPIO ( Ethernet, GPIO, SDCARD)/GPIO13: J8.33, Module1.28 (GPIO13)
/CM5_GPIO ( Ethernet, GPIO, SDCARD)/GPIO14: J8.8, Module1.55 (GPIO14)
/CM5_GPIO ( Ethernet, GPIO, SDCARD)/GPIO15: J8.10, Module1.51 (GPIO15)
/CM5_GPIO ( Ethernet, GPIO, SDCARD)/GPIO16: J8.36, Module1.29 (GPIO16)
/CM5_GPIO ( Ethernet, GPIO, SDCARD)/GPIO17: J8.11, Module1.50 (GPIO17)
/CM5_GPIO ( Ethernet, GPIO, SDCARD)/GPIO18: J8.12, Module1.49 (GPIO18)
/CM5_GPIO ( Ethernet, GPIO, SDCARD)/GPIO19: J8.35, Module1.26 (GPIO19)
/CM5_GPIO ( Ethernet, GPIO, SDCARD)/GPIO20: J8.38, Module1.27 (GPIO20)
/CM5_GPIO ( Ethernet, GPIO, SDCARD)/GPIO21: J8.40, Module1.25 (GPIO21)
/CM5_GPIO ( Ethernet, GPIO, SDCARD)/GPIO22: J8.15, Module1.46 (GPIO22)
/CM5_GPIO ( Ethernet, GPIO, SDCARD)/GPIO23: J8.16, Module1.47 (GPIO23)
/CM5_GPIO ( Ethernet, GPIO, SDCARD)/GPIO24: J8.18, Module1.45 (GPIO24)
/CM5_GPIO ( Ethernet, GPIO, SDCARD)/GPIO25: J8.22, Module1.41 (GPIO25)
/CM5_GPIO ( Ethernet, GPIO, SDCARD)/GPIO26: J8.37, Module1.24 (GPIO26)
/CM5_GPIO ( Ethernet, GPIO, SDCARD)/GPIO27: J8.13, Module1.48 (GPIO27)
/CM5_GPIO ( Ethernet, GPIO, SDCARD)/GPIO_VREF: Module1.78 (GPIO_VREF(1.8v/3.3v_Input)), R4.2, R5.2; also elsewhere on the board
/CM5_GPIO ( Ethernet, GPIO, SDCARD)/ID_SC: J8.28, Module1.35 (ID_SC); also elsewhere on the board
/CM5_GPIO ( Ethernet, GPIO, SDCARD)/ID_SD: J8.27, Module1.36 (ID_SD); also elsewhere on the board
/CM5_GPIO ( Ethernet, GPIO, SDCARD)/PMIC_ENABLE: J2.12, Module1.99 (PMIC_ENABLE)
/CM5_GPIO ( Ethernet, GPIO, SDCARD)/PWM: J14.2, Module1.19 (FAN_PWM), R11.2, TP2.1
/CM5_GPIO ( Ethernet, GPIO, SDCARD)/PWR_BUT: J2.14, Module1.92 (PWR_BUT), SW1.1
/CM5_GPIO ( Ethernet, GPIO, SDCARD)/SD_CLK: J7.5 (CLK), Module1.57 (SD_CLK)
/CM5_GPIO ( Ethernet, GPIO, SDCARD)/SD_CMD: J7.3 (CMD), Module1.62 (SD_CMD)
/CM5_GPIO ( Ethernet, GPIO, SDCARD)/SD_DAT0: J7.7 (DAT0), Module1.63 (SD_DAT0)
/CM5_GPIO ( Ethernet, GPIO, SDCARD)/SD_DAT1: J7.8 (DAT1), Module1.67 (SD_DAT1)
/CM5_GPIO ( Ethernet, GPIO, SDCARD)/SD_DAT2: J7.1 (DAT2), Module1.69 (SD_DAT2)
/CM5_GPIO ( Ethernet, GPIO, SDCARD)/SD_DAT3: J7.2 (DAT3/CD), Module1.61 (SD_DAT3)
/CM5_GPIO ( Ethernet, GPIO, SDCARD)/SD_PWR: C5.1, J7.4 (VDD), U18.1 (OUT)
/CM5_GPIO ( Ethernet, GPIO, SDCARD)/SD_PWR_ON: Module1.75 (SD_PWR_ON), R13.2, U18.4 (EN)
/CM5_GPIO ( Ethernet, GPIO, SDCARD)/SYNC_OUT: J2.6, Module1.18 (Ethernet_SYNC_OUT(3.3v))
/CM5_GPIO ( Ethernet, GPIO, SDCARD)/TACHO: J14.4, Module1.16 (FAN_TACHO), TP4.1
/CM5_GPIO ( Ethernet, GPIO, SDCARD)/TR0_TAP: J9.3, U3.11 (VC1)
/CM5_GPIO ( Ethernet, GPIO, SDCARD)/TR1_TAP: J9.1, U3.12 (VC2)
/CM5_GPIO ( Ethernet, GPIO, SDCARD)/TR2_TAP: J9.2, U3.13 (VC3)
/CM5_GPIO ( Ethernet, GPIO, SDCARD)/TR3_TAP: J9.4, U3.14 (VC4)
/CM5_GPIO ( Ethernet, GPIO, SDCARD)/TRD0_N: Module1.10 (Ethernet_Pair0_N), U2.4 (D2+), U2.7, U3.2 (TRD0-)
/CM5_GPIO ( Ethernet, GPIO, SDCARD)/TRD0_P: Module1.12 (Ethernet_Pair0_P), U2.5 (D2-), U2.6, U3.1 (TRD0+)
/CM5_GPIO ( Ethernet, GPIO, SDCARD)/TRD1_N: Module1.6 (Ethernet_Pair1_N), U2.2 (D1-), U2.9, U3.6 (TRD1-)
/CM5_GPIO ( Ethernet, GPIO, SDCARD)/TRD1_P: Module1.4 (Ethernet_Pair1_P), U2.1 (D1+), U2.10, U3.3 (TRD1+)
/CM5_GPIO ( Ethernet, GPIO, SDCARD)/TRD2_N: Module1.9 (Ethernet_Pair2_N), U1.4 (D2+), U1.7, U3.8 (TRD2-)
/CM5_GPIO ( Ethernet, GPIO, SDCARD)/TRD2_P: Module1.11 (Ethernet_Pair2_P), U1.5 (D2-), U1.6, U3.7 (TRD2+)
/CM5_GPIO ( Ethernet, GPIO, SDCARD)/TRD3_N: Module1.5 (Ethernet_Pair3_N), U1.2 (D1-), U1.9, U3.10 (TRD3-)
/CM5_GPIO ( Ethernet, GPIO, SDCARD)/TRD3_P: Module1.3 (Ethernet_Pair3_P), U1.1 (D1+), U1.10, U3.9 (TRD3+)
/CM5_GPIO ( Ethernet, GPIO, SDCARD)/USBOTG: J2.10; also elsewhere on the board
/CM5_GPIO ( Ethernet, GPIO, SDCARD)/VBAT: BT1.1 (+), Module1.76 (VBAT)
/CM5_GPIO ( Ethernet, GPIO, SDCARD)/WL_nDis: J3.1, Module1.89 (WiFi_nDisable)
/CM5_GPIO ( Ethernet, GPIO, SDCARD)/nPWR_LED: Module1.95 (LED_nPWR), R10.2
/CM5_GPIO ( Ethernet, GPIO, SDCARD)/nRPIBOOT: J2.2, Module1.93 (nRPIBOOT)
/CM5_HighSpeed/SCL0: Module1.80 (SCL0); also elsewhere on the board
/CM5_HighSpeed/SDA0: Module1.82 (SDA0); also elsewhere on the board
GND: BT1.2 (-), C1.2, C5.2, J2.1, J2.3, J2.5, J2.7, J2.9, J2.11, J2.13, J3.2, J7.6 (VSS), J7.11 (SHIELD), J8.6, J8.9, J8.14, J8.20, J8.25, J8.30, J8.34, J8.39, J14.3, Module1.1 (GND), Module1.2 (GND), Module1.7 (GND), Module1.8 (GND), Module1.13 (GND), Module1.14 (GND), Module1.22 (GND), Module1.23 (GND), Module1.32 (GND), Module1.33 (GND), Module1.42 (GND), Module1.43 (GND), Module1.52 (GND), Module1.53 (GND), Module1.59 (GND), Module1.60 (GND), Module1.65 (GND), Module1.66 (GND), Module1.71 (GND), Module1.74 (GND), Module1.98 (GND), SW1.2, U1.3 (GND), U1.8 (GND), U2.3 (GND), U2.8 (GND), U3.19 (SHIELD), U3.20 (SHIELD), U18.2 (GND); also elsewhere on the board
unnamed: C1.1, U3.4 (CT), U3.5 (CT)
unnamed: D1.1 (K), R10.1, TP5.1
unnamed: D2.1 (K), R1.1, TP3.1
unnamed: Module1.21 (LED_nACT), R1.2
unnamed: R3.1, U3.18 (LEDG_K)
unnamed: R2.1, U3.16 (LEDY_K)

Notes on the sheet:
40Way GPIO Header
Activity LED
R2 : Simplify nPWR_LED Drive
FAN connector
R2 : Add R13 to support CM4Lite
Ethernet POE Protection
GPIO Voltage select
R2 : Pullup added for Fans that don't have a strong internal pullup
Not Fitted header
POE Header
Force RPIBOOT = Jumper Pins 1-2
PWR LED
Ethernet
CM5Lite SDCARD I/F

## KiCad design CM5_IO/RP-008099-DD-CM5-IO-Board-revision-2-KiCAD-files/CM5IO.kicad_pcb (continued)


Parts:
C2, C7, C8: 10u; C_0805_2012Metric; Part Description 10uF 10% 10V Ceramic Capacitor X7R 0805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
C3: 100uF; CP_EIA-7343-31_Kemet-D; Part Description Capacitor, SP-Cap, 100u, 6.3V, 15mR ESR
C12, C13: 100n; C_0402_1005Metric; Part Description 0.1uF 10% 16V Ceramic Capacitor X7R 040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
J5, J16: Conn_01x22_Female; Hirose_FH12-22S-0.5SH_1x22-1MP_P0.50mm_Horizontal; Part Description 22 Position FFC, FPC Connector Contacts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
J6: THD-02-R; PinHeader_2x02_P2.54mm_Vertical; Part Description PinHeader_2x02_P2.54mm_Vertical
J10, J22: 690-019-298-412; EDAC 690-019-298-412; Part Description HDMI Connector, Right Angle, 19 Contact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
J12: USB3_A; MTCONN_UBAF30-D2011; Part Description Dual USB 3 connector
Module1: ComputeModule5-CM5; Raspberry-Pi-5-Compute-Module; Part Description 100 Position Connector Receptacle, Cent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
R6, R7, R8: 2.2K 1%; R_0402_1005Metric; Part Description Resistor 2.2K M1005 1% 63mW
R12: 15K 1%; R_0402_1005Metric; Part Description Resistor 15K M1005 1% 63mW
U6: AP22653W6; SOT-23-6; Part Description Power Switch/Driver 1:1 P-Channel 2.1A 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
U12: RT9742SNGV; TSOT-23_HandSoldering; Part Description Power Switch/Driver 1:1 N-Channel 500mA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

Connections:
/+3.3v: J5.22, J16.22, R8.1; also elsewhere on the board
/+5v: C2.1, C12.1, U6.1 (IN), U12.1 (IN); also elsewhere on the board
/CM5_GPIO ( Ethernet, GPIO, SDCARD)/CAM_GPIO0: J5.17; also elsewhere on the board
/CM5_GPIO ( Ethernet, GPIO, SDCARD)/CAM_GPIO1: J5.18; also elsewhere on the board
/CM5_GPIO ( Ethernet, GPIO, SDCARD)/GPIO_VREF: R6.1, R7.1; also elsewhere on the board
/CM5_GPIO ( Ethernet, GPIO, SDCARD)/ID_SC: J6.1; also elsewhere on the board
/CM5_GPIO ( Ethernet, GPIO, SDCARD)/ID_SD: J6.3; also elsewhere on the board
/CM5_GPIO ( Ethernet, GPIO, SDCARD)/USBOTG: Module1.101 (USB_OTG_ID); also elsewhere on the board
/CM5_HighSpeed/DPHY0_C_N: J5.8, Module1.127 (MIPI0_C_N)
/CM5_HighSpeed/DPHY0_C_P: J5.9, Module1.129 (MIPI0_C_P)
/CM5_HighSpeed/DPHY0_D0_N: J5.2, Module1.115 (MIPI0_D0_N)
/CM5_HighSpeed/DPHY0_D0_P: J5.3, Module1.117 (MIPI0_D0_P)
/CM5_HighSpeed/DPHY0_D1_N: J5.5, Module1.121 (MIPI0_D1_N)
/CM5_HighSpeed/DPHY0_D1_P: J5.6, Module1.123 (MIPI0_D1_P)
/CM5_HighSpeed/DPHY0_D2_N: J5.11, Module1.133 (MIPI0_D2_N)
/CM5_HighSpeed/DPHY0_D2_P: J5.12, Module1.135 (MIPI0_D2_P)
/CM5_HighSpeed/DPHY0_D3_N: J5.14, Module1.139 (MIPI0_D3_N)
/CM5_HighSpeed/DPHY0_D3_P: J5.15, Module1.141 (MIPI0_D3_P)
/CM5_HighSpeed/DPHY1_C_N: J16.8, Module1.187 (MIPI1_C_N)
/CM5_HighSpeed/DPHY1_C_P: J16.9, Module1.189 (MIPI1_C_P)
/CM5_HighSpeed/DPHY1_D0_N: J16.2, Module1.175 (MIPI1_D0_N)
/CM5_HighSpeed/DPHY1_D0_P: J16.3, Module1.177 (MIPI1_D0_P)
/CM5_HighSpeed/DPHY1_D1_N: J16.5, Module1.181 (MIPI1_D1_N)
/CM5_HighSpeed/DPHY1_D1_P: J16.6, Module1.183 (MIPI1_D1_P)
/CM5_HighSpeed/DPHY1_D2_N: J16.11, Module1.193 (MIPI1_D2_N)
/CM5_HighSpeed/DPHY1_D2_P: J16.12, Module1.195 (MIPI1_D2_P)
/CM5_HighSpeed/DPHY1_D3_N: J16.14, Module1.194 (MIPI1_D3_N)
/CM5_HighSpeed/DPHY1_D3_P: J16.15, Module1.196 (MIPI1_D3_P)
/CM5_HighSpeed/HDMI0_CEC: J22.13 (CEC), Module1.151 (HDMI0_CEC)
/CM5_HighSpeed/HDMI0_CK_N: J22.12 (CK-), Module1.190 (HDMI0_CLK_N)
/CM5_HighSpeed/HDMI0_CK_P: J22.10 (CK+), Module1.188 (HDMI0_CLK_P)
/CM5_HighSpeed/HDMI0_D0_N: J22.9 (D0-), Module1.184 (HDMI0_TX0_N)
/CM5_HighSpeed/HDMI0_D0_P: J22.7 (D0+), Module1.182 (HDMI0_TX0_P)
/CM5_HighSpeed/HDMI0_D1_N: J22.6 (D1-), Module1.178 (HDMI0_TX1_N)
/CM5_HighSpeed/HDMI0_D1_P: J22.4 (D1+), Module1.176 (HDMI0_TX1_P)
/CM5_HighSpeed/HDMI0_D2_N: J22.3 (D2-), Module1.172 (HDMI0_TX2_N)
/CM5_HighSpeed/HDMI0_D2_P: J22.1 (D2+), Module1.170 (HDMI0_TX2_P)
/CM5_HighSpeed/HDMI0_HOTPLUG: J22.19 (HPD/HEAC-), Module1.153 (HDMI0_HOTPLUG)
/CM5_HighSpeed/HDMI0_SCL: J22.15 (SCL), Module1.200 (HDMI0_SCL)
/CM5_HighSpeed/HDMI0_SDA: J22.16 (SDA), Module1.199 (HDMI0_SDA)
/CM5_HighSpeed/HDMI1_CEC: J10.13 (CEC), Module1.149 (HDMI1_CEC)
/CM5_HighSpeed/HDMI1_CK_N: J10.12 (CK-), Module1.166 (HDMI1_CLK_N)
/CM5_HighSpeed/HDMI1_CK_P: J10.10 (CK+), Module1.164 (HDMI1_CLK_P)
/CM5_HighSpeed/HDMI1_D0_N: J10.9 (D0-), Module1.160 (HDMI1_TX0_N)
/CM5_HighSpeed/HDMI1_D0_P: J10.7 (D0+), Module1.158 (HDMI1_TX0_P)
/CM5_HighSpeed/HDMI1_D1_N: J10.6 (D1-), Module1.154 (HDMI1_TX1_N)
/CM5_HighSpeed/HDMI1_D1_P: J10.4 (D1+), Module1.152 (HDMI1_TX1_P)
/CM5_HighSpeed/HDMI1_D2_N: J10.3 (D2-), Module1.148 (HDMI1_TX2_N)
/CM5_HighSpeed/HDMI1_D2_P: J10.1 (D2+), Module1.146 (HDMI1_TX2_P)
/CM5_HighSpeed/HDMI1_HOTPLUG: J10.19 (HPD/HEAC-), Module1.143 (HDMI1_HOTPLUG)
/CM5_HighSpeed/HDMI1_SCL: J10.15 (SCL), Module1.147 (HDMI1_SCL)
/CM5_HighSpeed/HDMI1_SDA: J10.16 (SDA), Module1.145 (HDMI1_SDA)
/CM5_HighSpeed/HDMI_5v: C13.1, J10.18 (+5V), J22.18 (+5V), U12.2 (OUT)
/CM5_HighSpeed/PCIE_CLK_N: Module1.112 (PCIe_CLK_N); also elsewhere on the board
/CM5_HighSpeed/PCIE_CLK_P: Module1.110 (PCIe_CLK_P); also elsewhere on the board
/CM5_HighSpeed/PCIE_PWR_EN: Module1.106 (PCIE_PWR_EN); also elsewhere on the board
/CM5_HighSpeed/PCIE_RX_N: Module1.118 (PCIe_RX_N); also elsewhere on the board
/CM5_HighSpeed/PCIE_RX_P: Module1.116 (PCIe_RX_P); also elsewhere on the board
/CM5_HighSpeed/PCIE_TX_N: Module1.124 (PCIe_TX_N); also elsewhere on the board
/CM5_HighSpeed/PCIE_TX_P: Module1.122 (PCIe_TX_P); also elsewhere on the board
/CM5_HighSpeed/PCIE_nCLKREQ: Module1.102 (PCIe_nCLKREQ); also elsewhere on the board
/CM5_HighSpeed/PCIE_nRST: Module1.109 (PCIe_nRST); also elsewhere on the board
/CM5_HighSpeed/PCIE_nWAKE: Module1.104 (PCIE_nWAKE); also elsewhere on the board
/CM5_HighSpeed/SCL0: J5.20; also elsewhere on the board
/CM5_HighSpeed/SCL1: J6.2, J16.20, R7.2
/CM5_HighSpeed/SDA0: J5.21; also elsewhere on the board
/CM5_HighSpeed/SDA1: J6.4, J16.21, R6.2
/CM5_HighSpeed/USB3-0-D_N: J12.A2 (D-), Module1.136 (USB3-0-D_N)
/CM5_HighSpeed/USB3-0-D_P: J12.A3 (D+), Module1.134 (USB3-0-D_P)
/CM5_HighSpeed/USB3-0-RX_N: J12.A6 (SSRX+), Module1.128 (USB3-0-RX_N)
/CM5_HighSpeed/USB3-0-RX_P: J12.A5 (SSRX-), Module1.130 (USB3-0-RX_P)
/CM5_HighSpeed/USB3-0-TX_N: J12.A9 (SSTX+), Module1.140 (USB3-0-TX_N)
/CM5_HighSpeed/USB3-0-TX_P: J12.A8 (SSTX-), Module1.142 (USB3-0-TX_P)
/CM5_HighSpeed/USB3-1-D_N: J12.B2 (D-), Module1.165 (USB3-1-D_N)
/CM5_HighSpeed/USB3-1-D_P: J12.B3 (D+), Module1.163 (USB3-1-D_P)
/CM5_HighSpeed/USB3-1-RX_N: J12.B6 (SSRX+), Module1.157 (USB3-1-RX_N)
/CM5_HighSpeed/USB3-1-RX_P: J12.B5 (SSRX-), Module1.159 (USB3-1-RX_P)
/CM5_HighSpeed/USB3-1-TX_N: J12.B9 (SSTX+), Module1.169 (USB3-1-TX_N)
/CM5_HighSpeed/USB3-1-TX_P: J12.B8 (SSTX-), Module1.171 (USB3-1-TX_P)
/CM5_HighSpeed/VBUS: C3.1, C7.1, C8.1, J12.A1 (VBUS), J12.B1 (VBUS), U6.6 (OUT)
/CM5_HighSpeed/VBUS_EN: Module1.111 (VBUS_EN), U6.3 (EN)
/USB2_N: Module1.103 (USB2_N); also elsewhere on the board
/USB2_P: Module1.105 (USB2_P); also elsewhere on the board
GND: C2.2, C3.2, C7.2, C8.2, C12.2, C13.2, J5.1, J5.4, J5.7, J5.10, J5.13, J5.16, J5.19, J10.2 (D2S), J10.5 (D1S), J10.8 (D0S), J10.11 (CKS), J10.17 (GND), J10.SH1 (SH), J10.SH2 (SH), J10.SH3 (SH), J10.SH4 (SH), J12.10 (SHIELD), J12.A4 (GND), J12.A7 (DRAIN), J12.B4 (GND), J12.B7 (DRAIN), J16.1, J16.4, J16.7, J16.10, J16.13, J16.16, J16.19, J22.2 (D2S), J22.5 (D1S), J22.8 (D0S), J22.11 (CKS), J22.17 (GND), J22.SH1 (SH), J22.SH2 (SH), J22.SH3 (SH), J22.SH4 (SH), Module1.107 (GND), Module1.108 (GND), Module1.113 (GND), Module1.114 (GND), Module1.119 (GND), Module1.120 (GND), Module1.125 (GND), Module1.126 (GND), Module1.131 (GND), Module1.132 (GND), Module1.137 (GND), Module1.138 (GND), Module1.144 (GND), Module1.150 (GND), Module1.155 (GND), Module1.156 (GND), Module1.161 (GND), Module1.162 (GND), Module1.167 (GND), Module1.168 (GND), Module1.173 (GND), Module1.174 (GND), Module1.179 (GND), Module1.180 (GND), Module1.185 (GND), Module1.186 (GND), Module1.191 (GND), Module1.192 (GND), Module1.197 (GND), Module1.198 (GND), R12.2, U6.2 (GND), U12.3 (GND); also elsewhere on the board
unnamed: J16.17, R8.2
unnamed: R12.1, U6.5 (ILIM)

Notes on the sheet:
USB 3 Pairs P/N swapped to help routing
Jumpers to be fitted if DPHY1 is used
Current Limit switch
DSI/CSI Connectors
Stacked USB connectors


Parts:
C4, C6, C14, C15, C16, C17: 10u; C_0805_2012Metric; Part Description 10uF 10% 10V Ceramic Capacitor X7R 0805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
C10, C19: 100n; C_0402_1005Metric; Part Description 0.1uF 10% 16V Ceramic Capacitor X7R 040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
C11: 4.7nF; C_0402_1005Metric; Part Description 4.7nF capacitor 0402
D3: LED Green; LED_0603_1608Metric; Part Description Green 572nm LED Indication - Discrete 2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
J4: Bus_M.2_Socket_M; M.2 M Key socket; Part Description M.2 M Key connector
L1: 2.2uH; L_Bourns_SRP5030CC; Part Description Inductor, SMT, 2520, 2u2, IRMS=7A, ISAT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
M1: M.2 Screw; Part Description M.2 Screw
M2, M3, M4, M5: M.2 Solder Nut; Part Description Solder nut for M.2 slot
R14: 100K 1%; R_0402_1005Metric; Part Description Resistor 100K M1005 1% 63mW
R15: 10K 1%; R_0402_1005Metric; Part Description Resistor 10K M1005 1% 63mW
R16: 2.2K 1%; R_0402_1005Metric; Part Description Resistor 2.2K M1005 1% 63mW
R17: 1k; R_0402_1005Metric; Part Description Resistor 1K M1005 1% 63mW
TP1: TestPoint; TestPoint_Pad_2.0x2.0mm; Part Description Test point; not fitted
U7: ASEK-32.768KHZ-L-R-T; Crystal_SMD_3225-4Pin_3.2x2.5mm; Part Description 32KHz Xtal oscilator
U8: AP3441SHE-7B; DFN-8-1EP_2x2mm_P0.5mm_EP1.05x1.75mm; Part Description 3A DC-DC converter

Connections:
/+5v: C4.1, C6.1, C10.1, U8.3 (VIN); also elsewhere on the board
/CM5_HighSpeed/PCIE_CLK_N: J4.53 (REFCLKn); also elsewhere on the board
/CM5_HighSpeed/PCIE_CLK_P: J4.55 (REFCLKp); also elsewhere on the board
/CM5_HighSpeed/PCIE_PWR_EN: R14.1, U8.7 (EN); also elsewhere on the board
/CM5_HighSpeed/PCIE_RX_N: J4.43 (PETp0); also elsewhere on the board
/CM5_HighSpeed/PCIE_RX_P: J4.41 (PETn0); also elsewhere on the board
/CM5_HighSpeed/PCIE_TX_N: J4.49 (PERp0); also elsewhere on the board
/CM5_HighSpeed/PCIE_TX_P: J4.47 (PERn0); also elsewhere on the board
/CM5_HighSpeed/PCIE_nCLKREQ: J4.52 (~CLKREQ); also elsewhere on the board
/CM5_HighSpeed/PCIE_nRST: J4.50 (~PERST); also elsewhere on the board
/CM5_HighSpeed/PCIE_nWAKE: J4.54 (~PEWAKE); also elsewhere on the board
/PCIe-M2/FB: C11.2, R15.2, R16.1, U8.1 (FB)
/PCIe-M2/M2_3v3: C11.1, C14.1, C15.1, C16.1, C17.1, C19.1, D3.2 (A), J4.2 (3.3V), J4.4 (3.3V), J4.12 (3.3V), J4.14 (3.3V), J4.16 (3.3V), J4.18 (3.3V), J4.70 (3.3V), J4.72 (3.3V), J4.74 (3.3V), L1.2, R15.1, U7.1 (EN), U7.4 (VDD)
GND: C4.2, C6.2, C10.2, C14.2, C15.2, C16.2, C17.2, C19.2, J4.1 (GND), J4.3 (GND), J4.9 (GND), J4.15 (GND), J4.21 (GND), J4.27 (GND), J4.33 (GND), J4.39 (GND), J4.45 (GND), J4.51 (GND), J4.57 (GND), J4.71 (GND), J4.73 (GND), J4.75 (GND), J4.M1 (GND2230), J4.M2 (GND2242), J4.M3 (GND2260), J4.M4 (GND2280), J4.S1, J4.S2, R14.2, R16.2, U7.2 (GND), U8.4 (PGND), U8.8 (SGND), U8.9 (PAD); also elsewhere on the board
unnamed: D3.1 (K), R17.1, TP1.1
unnamed: J4.10 (DAS/~DSS/~LED1), R17.2
unnamed: J4.68 (SUSCLK), U7.3 (Out)
unnamed: L1.1, U8.6 (LX)

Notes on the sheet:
Activity LED

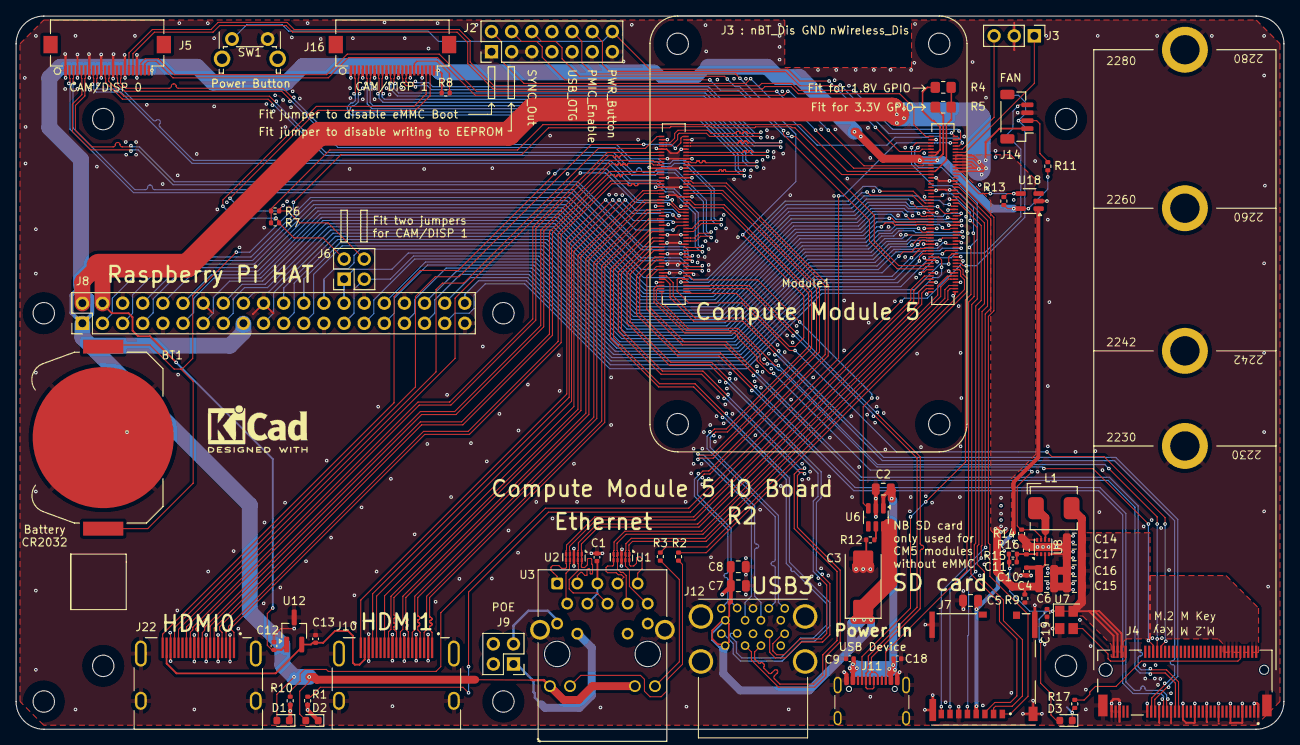
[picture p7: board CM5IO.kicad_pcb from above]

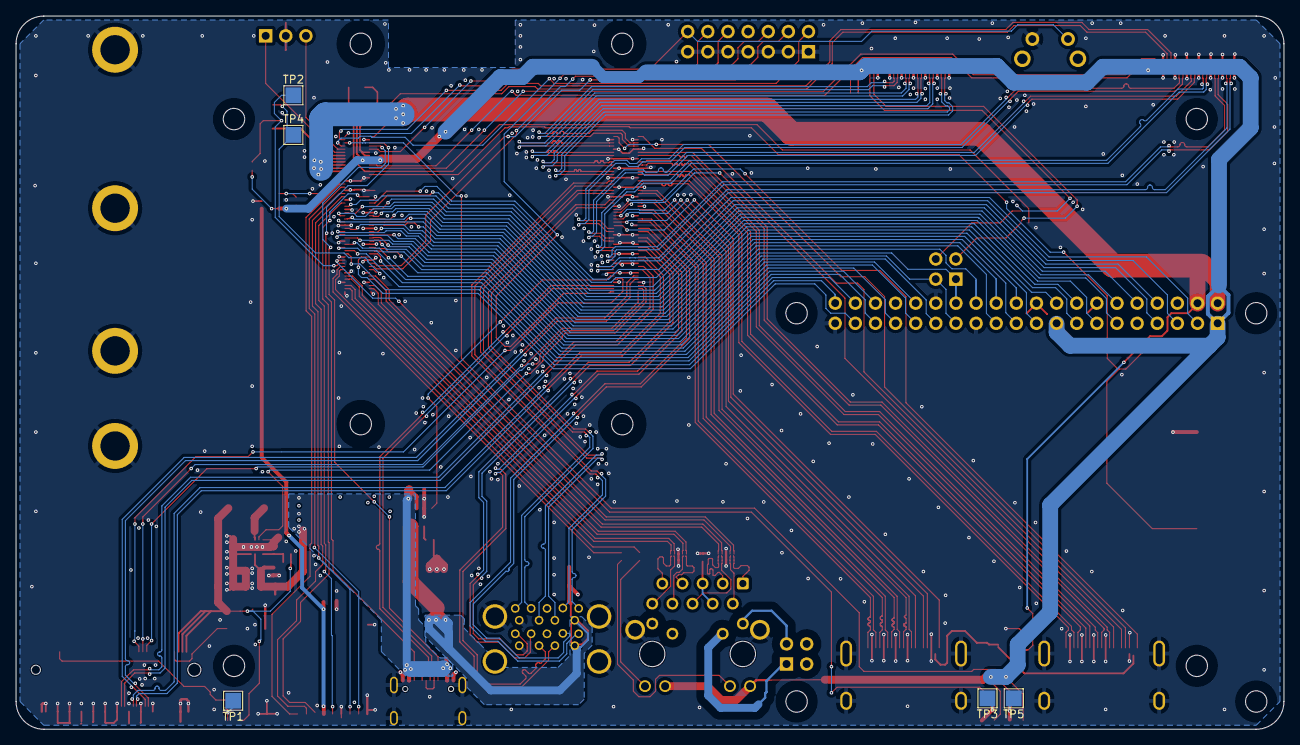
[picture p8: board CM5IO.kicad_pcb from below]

Board: 4 copper layers, 160.0 x 90.0 mm, 78 parts (5 on the bottom side), 160 nets.

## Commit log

2026-02-04 update gnss
    [gnss.kicad_sch]
2026-02-22 Revise README with updated specs and power details
    Updated specifications and power system details for KB-01 bike computer. Enhanced description and added new features for sensors, battery, and architecture.

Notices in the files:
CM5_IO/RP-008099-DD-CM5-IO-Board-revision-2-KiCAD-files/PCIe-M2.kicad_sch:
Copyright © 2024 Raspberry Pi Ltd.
